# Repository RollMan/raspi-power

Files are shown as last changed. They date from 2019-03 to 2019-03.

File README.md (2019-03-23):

# Raspi-Power
## What is this?
This circuit keeps power supply to a raspberry pi for a second after the main power is down to shut down safely.. The functionalities are almost same as a UPS, but this is specialized to mount a car. This is useful for broadcasting your driving scenary, for example.

## How it works?
A car has two (strictly three) outlets: direct to battery and ACC. After you turn off an engine, ACC also turns off. This circuit detects that, and keep the power from battery directly while the raspberry pi is shutting down.

## Environment
- [kicad](http://kicad-pcb.org/) to see this circuit

## Misc
- A OKL\_T footprint thanks to (stm32f1/stm32-board)[https://github.com/stm32f1/stm32_board]

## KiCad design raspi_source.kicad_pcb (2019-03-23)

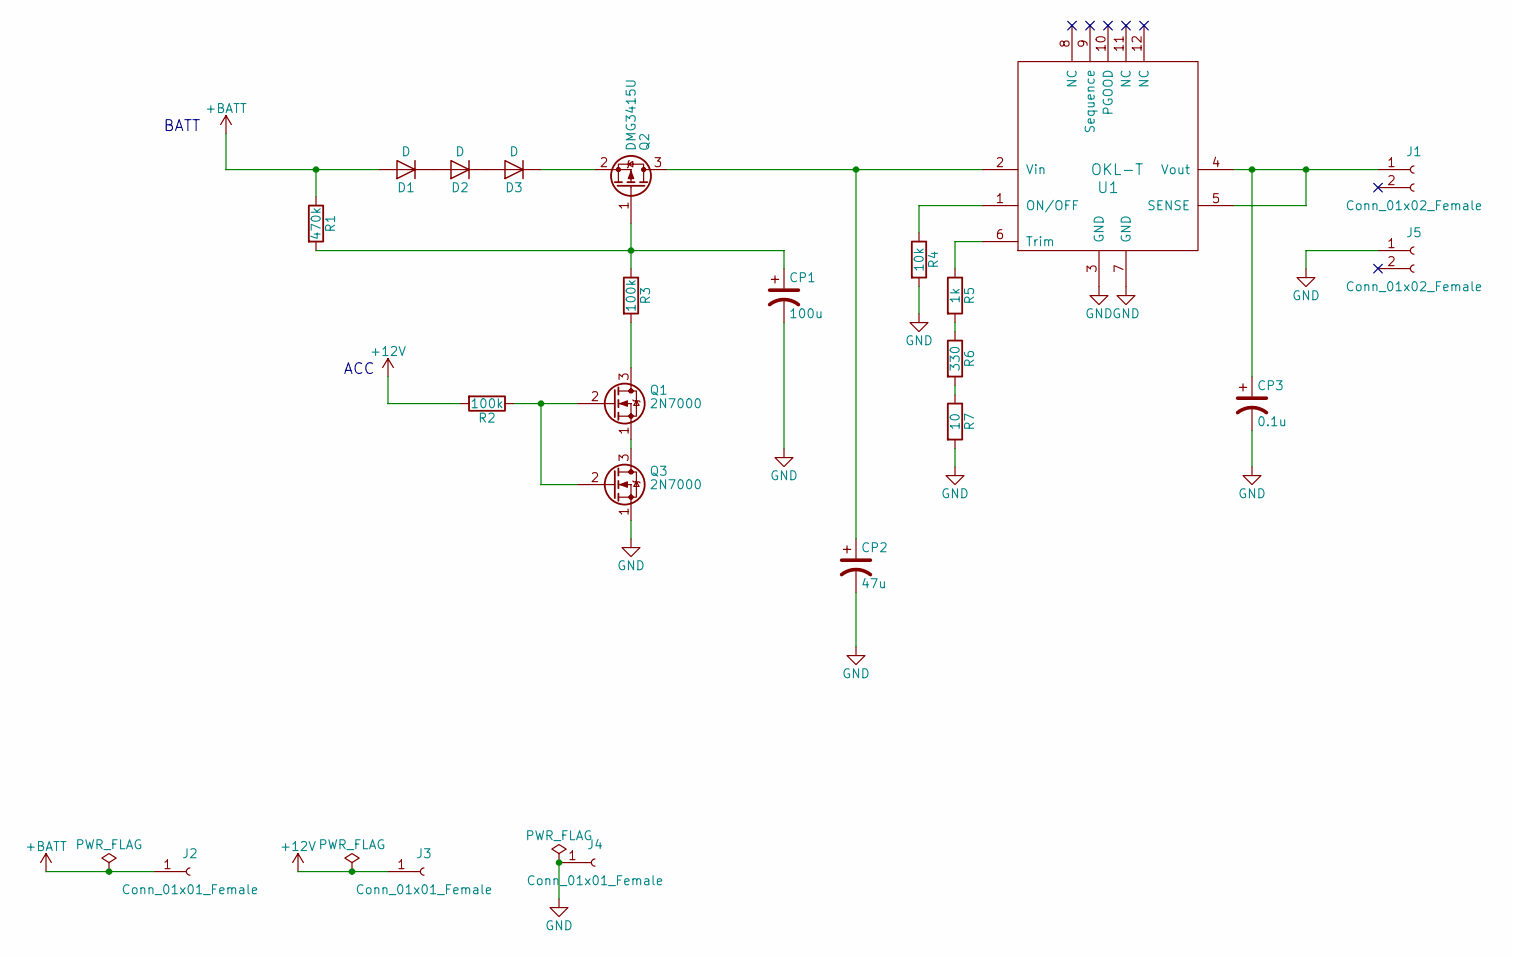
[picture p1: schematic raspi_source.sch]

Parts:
CP1: 100u; CP_Radial_Tantal_D4.5mm_P2.50mm
CP2: 47u; CP_Radial_Tantal_D4.5mm_P2.50mm
CP3: 0.1u; CP_Radial_Tantal_D4.5mm_P2.50mm
D1, D2, D3: D; D_A-405_P7.62mm_Horizontal
J1, J5: Conn_01x02_Female; Socket_Strip_Straight_1x02_Pitch2.54mm
J2, J3, J4: Conn_01x01_Female; Socket_Strip_Straight_1x01_Pitch2.54mm
Q1, Q3: 2N7000; TO-92_Molded_Narrow
Q2: DMG3415U; SOT-23
R1: 470k; R_Axial_DIN0204_L3.6mm_D1.6mm_P7.62mm_Horizontal
R2, R3: 100k; R_Axial_DIN0204_L3.6mm_D1.6mm_P7.62mm_Horizontal
R4: 10k; R_Axial_DIN0204_L3.6mm_D1.6mm_P7.62mm_Horizontal
R5: 1k; R_Axial_DIN0204_L3.6mm_D1.6mm_P7.62mm_Horizontal
R6: 330; R_Axial_DIN0204_L3.6mm_D1.6mm_P7.62mm_Horizontal
R7: 10; R_Axial_DIN0204_L3.6mm_D1.6mm_P7.62mm_Horizontal
U1: OKL-T; OKL_T6

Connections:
+12V: J3.1, R2.2
+BATT: D1.2 (A), J2.1, R1.1
GND: CP1.2, CP2.2, CP3.2, J4.1, J5.1, Q3.1 (S), R4.2, R7.2, U1.3 (GND), U1.7 (GND)
unnamed: CP1.1, Q2.1 (G), R1.2, R3.1
unnamed: CP2.1, Q2.3 (D), U1.2 (Vin)
unnamed: CP3.1, J1.1, U1.4 (Vout), U1.5 (SENSE)
unnamed: D1.1 (K), D2.2 (A)
unnamed: D2.1 (K), D3.2 (A)
unnamed: D3.1 (K), Q2.2 (S)
unnamed: Q1.1 (S), Q3.3 (D)
unnamed: Q1.2 (G), Q3.2 (G), R2.1
unnamed: Q1.3 (D), R3.2
unnamed: R4.1, U1.1 (ON/OFF)
unnamed: R5.1, U1.6 (Trim)
unnamed: R5.2, R6.1
unnamed: R6.2, R7.1

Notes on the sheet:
ACC
BATT

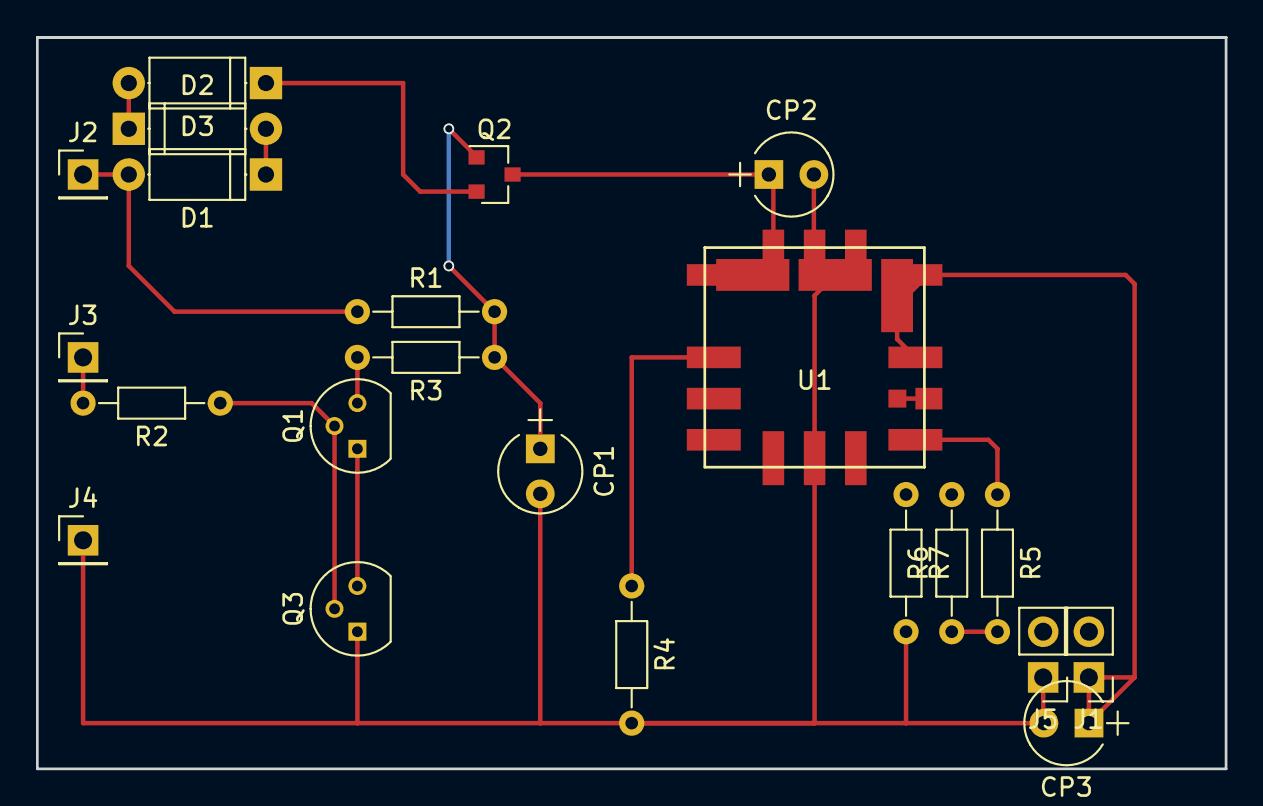
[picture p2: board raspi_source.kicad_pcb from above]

Board: 2 copper layers, 66.0 x 40.6 mm, 22 parts (0 on the bottom side), 16 nets.

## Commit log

2018-06-03 initial commit
    schematic had been created
    [raspi_source.kicad_pcb, raspi_source.sch]
2018-06-09 the scheme has been complete.
    test has been passed and the scheme was modified
    [raspi_source.sch]
2018-06-10 adjust dcdc register
    [raspi_source.sch]
2018-06-10 add footprint of new components
    [raspi_source.sch]
2018-06-10 expand footprints
    [raspi_source.kicad_pcb]
2018-06-10 wiring has been completed
    [raspi_source.kicad_pcb]
2018-06-10 move capaciter
    [raspi_source.kicad_pcb]
2018-06-10 fix something
    TODO: need find what i fixed
    [raspi_source.kicad_pcb]
